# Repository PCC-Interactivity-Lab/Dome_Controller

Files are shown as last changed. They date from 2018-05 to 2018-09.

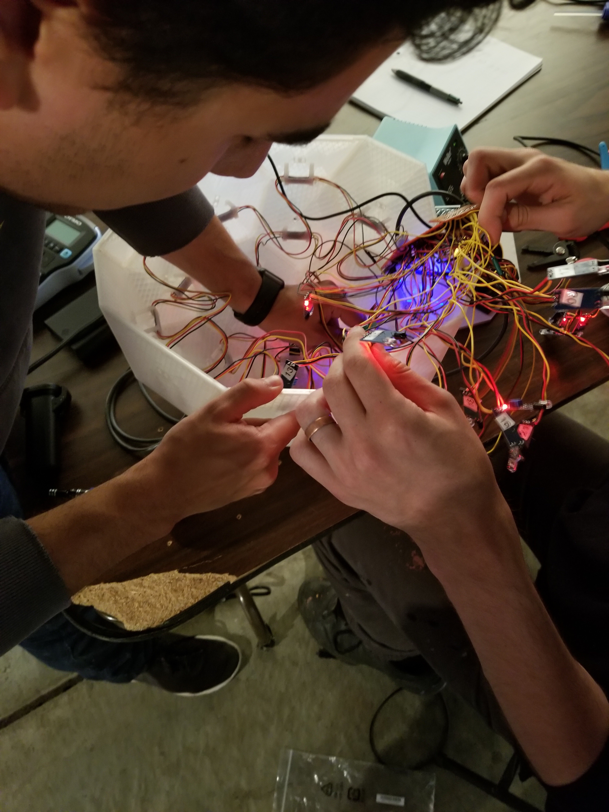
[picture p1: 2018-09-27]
Gallery/20180608_204740.jpg

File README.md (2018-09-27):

# Dome_Controller

The controller housing consists of 6 "IR Pentagon Panel" panels, 10 "IR Hexagon Panel" panels, and 5 "IR Half Hexagon Panels". Panels mate via slots and buiscuits. Each panel is equiped with an ifrared sensor, and corresponding Neopixel. The entierety of the controller sits on a rotary encoder.

When up and running, the Ir sensors trigger its corresponding neopixel, and sends OSC information. This code is known to run on an Adafruit Feather M0 with the ATWink1500. 

Included are; componant stls, as well as Creality CR10 gcode for tabs, single panels, and sets of panels. (e.g. "... x1, ...x3"), Adobe Illustrator files for laser cutting a base, and arduino code. 

A video of the controller in action can be found here https://vimeo.com/279008987

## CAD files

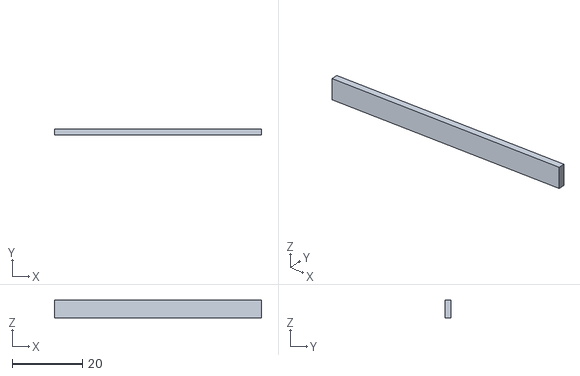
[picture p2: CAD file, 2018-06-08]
Componants Stls/Tab.stl
59.0 x 1.60 x 5.00

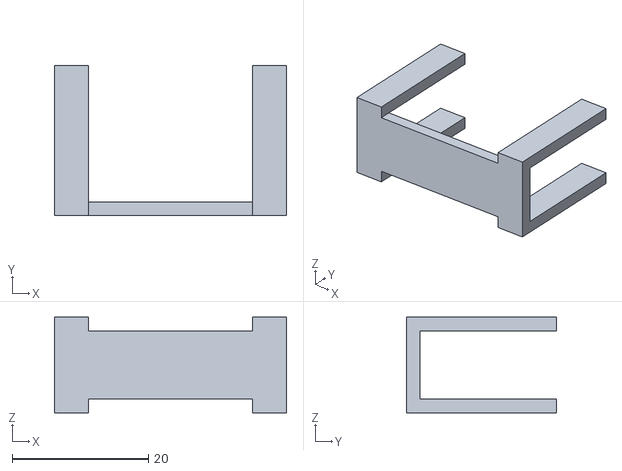
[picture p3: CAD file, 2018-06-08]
Componants Stls/Neopixel Mount.stl
34.0 x 22.0 x 14.0

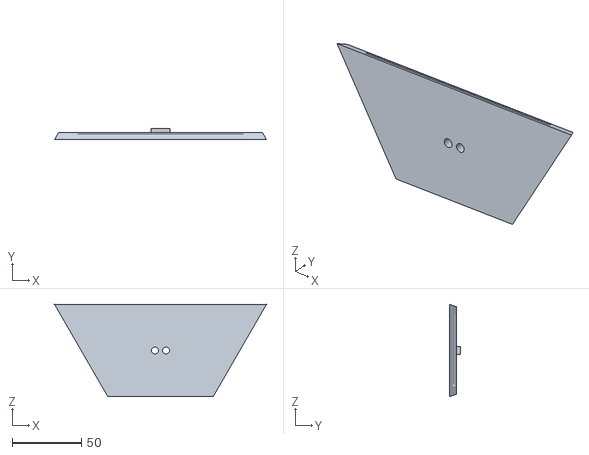
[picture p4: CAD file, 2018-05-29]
Componants Stls/IR Half Hex Panel.stl
152.9 x 8.00 x 66.6

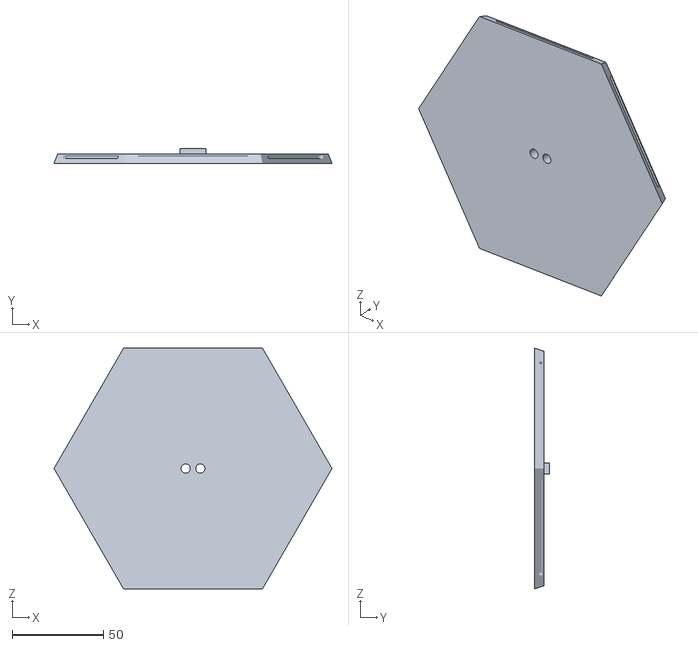
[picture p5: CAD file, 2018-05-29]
Componants Stls/IR Hexagon Panel.stl
151.9 x 8.00 x 131.6

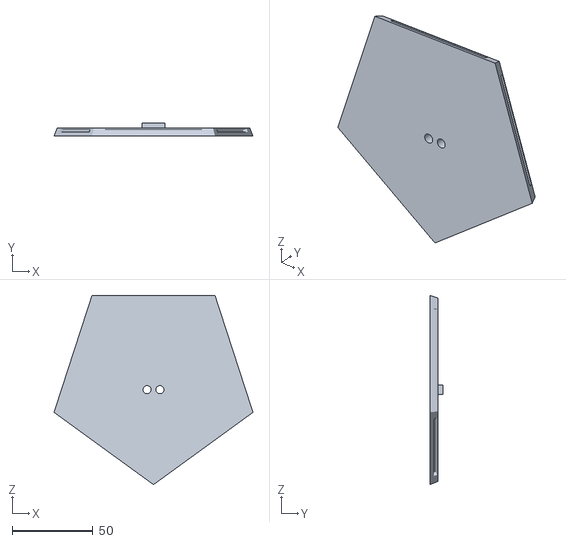
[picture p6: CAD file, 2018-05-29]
Componants Stls/IR Pentagon Panel.stl
123.3 x 8.00 x 117.3

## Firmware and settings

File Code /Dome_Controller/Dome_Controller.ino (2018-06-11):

// Dome Controller
// Creative Coding Capstone 2018
// Code by: Keanu Yokoyama, Quinn Jarvis-Holland
// Special Thanks to Jesse Mejia

//#include <OSCBoards.h>
#include <OSCBundle.h>
#include <OSCData.h>
#include <OSCMatch.h>
#include <OSCMessage.h>
#include <OSCTiming.h>
#include <SLIPEncodedSerial.h>
#include <SLIPEncodedUSBSerial.h>
#include <SPI.h>
#include <WiFi101.h>
#include <WiFiUdp.h>
#include <OSCMessage.h>

#define ENCODER_USE_INTERRUPTS

#define ENCODER_OPTIMIZE_INTERRUPTS
#include <Encoder.h>

#include <Adafruit_NeoPixel.h>
#ifdef __AVR__
#include <avr/power.h>
#endif

#define PIN            13

#define NUMPIXELS      21

// encoder pins
Encoder rotaryEnc(11, 12);

// OSC NETWORK STUFF
int status = WL_IDLE_STATUS;
char ssid[] = "PaulSwift"; //  your network SSID (name)
char pass[] = "thankyou";    // your network password (use for WPA, or use as key for WEP)

// the Arduino's IP (only for recieving)
// destination IP
IPAddress outIp1(192, 168, 1, 6 );//nolan
IPAddress outIp2(192, 168, 1, 8 );//keanu
IPAddress outIp3(192, 168, 1, 9 );//robert
const unsigned int outPort = 9999;

WiFiUDP Udp;

Adafruit_NeoPixel pixels = Adafruit_NeoPixel(NUMPIXELS, PIN, NEO_GRB + NEO_KHZ800);
//set a framerate like at 30 fps using a delay at end of the loop
int trig[NUMPIXELS];
int fade[NUMPIXELS];
int panel[NUMPIXELS];
int irPins[] = {15, 16, 17, 18, 19};

// Mux control pins
int s0 = 5;
int s1 = 6;
int s2 = 9;
int s3 = 10;

// Mux in “SIG” pin
int SIG_pin = 14;


byte r;
byte g;
byte b;

int fadeTime = 5; //fadetime in frames

int delayval = 0; //Seconds that it takes for Neopixel to fade

int frameCounter = 0;

void setup() {

  pixels.begin();
  pixels.show();

  pinMode(s0, OUTPUT);
  pinMode(s1, OUTPUT);
  pinMode(s2, OUTPUT);
  pinMode(s3, OUTPUT);

  digitalWrite(s0, LOW);
  digitalWrite(s1, LOW);
  digitalWrite(s2, LOW);
  digitalWrite(s3, LOW);

  digitalWrite(2, HIGH);

  Serial.begin(9600);

  WiFi.setPins(8, 7, 4); // CS, irq, rst

  if (WiFi.status() == WL_NO_SHIELD) {
    // Serial.println("WiFi shield not present");
    // don't continue:
    // while (true);

  }

  while ( status != WL_CONNECTED) {
    // Serial.print("Attempting to connect to SSID: ");
    // Serial.println(ssid);
    // Connect to WPA/WPA2 network. Change this line if using open or WEP network:
    status = WiFi.begin(ssid, pass);
    // wait 3 seconds for connection:
    // delay(2000);
  }

  // Serial.println("Connected to wifi");
  // printWiFiStatus();

  // Serial.println("\nStarting connection to server...");
  // if you get a connection, report back via serial:
  Udp.begin(outPort);


  //connection successful code (blink LED x3)
  //digitalWrite(13, HIGH);
  //   delay(100);
  // digitalWrite(13, LOW);
  //   delay(100);
  // digitalWrite(13, HIGH);
  //   delay(100);
  // digitalWrite(13, LOW);
  //   delay(100);
  // digitalWrite(13, HIGH);
  //   delay(1000);
  // digitalWrite(13, LOW);
}

// HSV Stuff taken and edited from https://gist.github.com/hdznrrd/656996
void HSV_to_RGB(float h, float s, float v, byte *r, byte *g, byte *b)
{
  int i;
  float f, p, q, t;

  h = max(0.0, min(360.0, h));
  s = max(0.0, min(100.0, s));
  v = max(0.0, min(100.0, v));

  s /= 100;
  v /= 100;

  if (s == 0) {
    // Achromatic (grey)
    *r = *g = *b = round(v * 255);
    return;
  }

  h /= 60; // sector 0 to 5
  i = floor(h);
  f = h - i; // factorial part of h
  p = v * (1 - s);
  q = v * (1 - s * f);
  t = v * (1 - s * (1 - f));
  switch (i) {
    case 0:
      *r = round(255 * v);
      *g = round(255 * t);
      *b = round(255 * p);
      break;
    case 1:
      *r = round(255 * q);
      *g = round(255 * v);
      *b = round(255 * p);
      break;
    case 2:
      *r = round(255 * p);
      *g = round(255 * v);
      *b = round(255 * t);
      break;
    case 3:
      *r = round(255 * p);
      *g = round(255 * q);
      *b = round(255 * v);
      break;
    case 4:
      *r = round(255 * t);
      *g = round(255 * p);
      *b = round(255 * v);
      break;
    default: // case 5:
      *r = round(255 * v);
      *g = round(255 * p);
      *b = round(255 * q);
  }
}

long rotaryPos  = -999;
long rotaryVal = 0;

void loop() {
  // put your main code here, to run repeatedly:

  frameCounter = frameCounter % 2400;
  for (int i = 0; i < NUMPIXELS; i++) {
    if (i <= 15) {
      panel[i] = readMux(i);
      if (panel[i] < 100) {
        trig[i] = HIGH;
        if (trig[i] = HIGH) {
          fade[i] = 100;
        }
      } else {
        trig[i] = LOW;
      }
    }// end of  if (i <= 15){

    if (i > 15) {
      panel[i] = analogRead(i - 1);
      if (panel[i] < 100) {
        trig[i] = HIGH;
        if (trig[i] = HIGH) {
          fade[i] = 100;
        }
      } else {
        trig[i] = LOW;
      }
    }

    float newHue = map(frameCounter, 0, 2400, 0, 359);
    //      Serial.println(newHue);
    if (fade[i] > 0) {
      fade[i] = fade[i] - fadeTime;
    }
    HSV_to_RGB(newHue, 100, fade[i], &r, &g, &b);
    pixels.setPixelColor(i, pixels.Color(r, g, b));
    pixels.show();
    frameCounter++;
  }// end for loop
  long newRotaryPos;
  newRotaryPos = rotaryEnc.read();

  if (newRotaryPos > rotaryPos) {
    rotaryVal++;
    rotaryPos = newRotaryPos;
    delay(10);
    // the message wants an OSC address as first argument
    OSCMessage msg("/rotary");
    msg.add(2);
    Udp.beginPacket(outIp1, outPort);
    msg.send(Udp); // send the bytes to the SLIP stream
    Udp.endPacket(); // mark the end of the OSC Packet
    Udp.beginPacket(outIp2, outPort);
    msg.send(Udp); // send the bytes to the SLIP stream
    Udp.endPacket(); // mark the end of the OSC Packet
    Udp.beginPacket(outIp3, outPort);
    msg.send(Udp); // send the bytes to the SLIP stream
    Udp.endPacket(); // mark the end of the OSC Packet
    msg.empty(); // free space occupied by message
  }

  else if (newRotaryPos < rotaryPos) {
    rotaryVal--;
    delay(10);
    OSCMessage msg("/rotary");
    msg.add(-2);
    Udp.beginPacket(outIp1, outPort);
    msg.send(Udp); // send the bytes to the SLIP stream
    Udp.endPacket(); // mark the end of the OSC Packet
    Udp.beginPacket(outIp2, outPort);
    msg.send(Udp); // send the bytes to the SLIP stream
    Udp.endPacket(); // mark the end of the OSC Packet
    Udp.beginPacket(outIp3, outPort);
    msg.send(Udp); // send the bytes to the SLIP stream
    Udp.endPacket(); // mark the end of the OSC Packet
    msg.empty(); // free space occupied by message

  }
  rotaryPos = newRotaryPos;
  OSCMessage msg("/IR");
  for (int i = 0; i < NUMPIXELS; i++) {
    msg.add(trig[i]);
  }
  Udp.beginPacket(outIp1, outPort);
  msg.send(Udp); // send the bytes to the SLIP stream
  Udp.endPacket(); // mark the end of the OSC Packet
  Udp.beginPacket(outIp2, outPort);
  msg.send(Udp); // send the bytes to the SLIP stream
  Udp.endPacket(); // mark the end of the OSC Packet
  Udp.beginPacket(outIp3, outPort);
  msg.send(Udp); // send the bytes to the SLIP stream
  Udp.endPacket(); // mark the end of the OSC Packet
  msg.empty(); // free space occupied by message
  delay(10);
}

int readMux(int channel) {
  int controlPin[] = {s0, s1, s2, s3};
  int muxChannel[16][4] = {
    {0, 0, 0, 0}, //channel 0
    {1, 0, 0, 0}, //channel 1
    {0, 1, 0, 0}, //channel 2
    {1, 1, 0, 0}, //channel 3
    {0, 0, 1, 0}, //channel 4
    {1, 0, 1, 0}, //channel 5
    {0, 1, 1, 0}, //channel 6
    {1, 1, 1, 0}, //channel 7
    {0, 0, 0, 1}, //channel 8
    {1, 0, 0, 1}, //channel 9
    {0, 1, 0, 1}, //channel 10
    {1, 1, 0, 1}, //channel 11
    {0, 0, 1, 1}, //channel 12
    {1, 0, 1, 1}, //channel 13
    {0, 1, 1, 1}, //channel 14
    {1, 1, 1, 1} //channel 15
  };
  // loop through the 4 sig
  for (int i = 0; i < 4; i ++) {
    digitalWrite(controlPin[i], muxChannel[channel][i]);
  }
  // read the value at the SIG pin
  int val = analogRead(SIG_pin);
  // return the value
  return val;
}

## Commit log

2018-04-17 Added STLs
    [Half Hexagon Panel v3.stl, Hexagon Panel V4.stl, Pentagon Panel v3.stl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]
2018-04-19 Updated STLs
    Changed the angles of the panels
    [Half Hex Panel V2.stl, Half Hexagon Panel v3.stl, Hexagon Panel V2.stl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]
2018-05-24 G code, New Stls
    New Stls were added, along with their g code. Readme also updated.
    [Half Hex Panel V2.stl, Hexagon Panel V2.stl, IR Half Hexagon Panel.stl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]
2018-05-29 New Stls & Gcode
    Componants and gcode updated for the larger IR sensors.
    [IR Half Hex Panel.stl, IR Half Hexagon Panel.stl, IR Hexagon Panel.stl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]
2018-06-08 Arduino
    Added Arduino code, and updated README.
    [Neopixel Mount.stl, Tab.stl]
2018-06-11 Base laser cut added
    Adobe Illustrator files for laser cut base added, Plaque panel added, README updated.
2018-06-11 Arduino Code Updated
    Updated the Arduino Code
